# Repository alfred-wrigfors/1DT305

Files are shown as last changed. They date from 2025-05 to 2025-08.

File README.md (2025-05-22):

# 1DT305
Summer 2025 - Applied IoT

> [!NOTE]
> I, the author, have multiple years of experience in both embedded hardware design and software development. The level of complexity of this project is not reasonable for a beginner IoT-project!

## Introduction
With family living close to the Vikhög marina, there is the constant question wether or not the condition in/around the marina is appropriate for going swimming. It is mostly the water temperature and levels of wind that are of interest. Insight into the conditions in the marina would greatly increase the likelihood of spontaneous and enjoyable swims, while also helping to avoid unpleasant surprises - such as unexpected cold water or strong winds. Rather than relying on regional forecasts, a localized monitoring system would offer a much more accurate and timely solution.

This project aims to provide current and up-to-date temperature readings, for both the water and air, accross the marina and an overall wind speed and heading reading. The goal is to distribute 2-4 battery- and solar powered sensor-stations at the most popular areas for going swimming, communicating wirelessly with a base-station that is connected to the internet and sending the data to a remote server that provides the information (both current and historic) in a simple and intuitive web-interface.

## Goals and constraints
Some overall goals for the project:
 - Server / web interface containerized to run in a Docker container.
 - The base station and the mobile units should be electronically identical.
 - Hardware designed to be fully assebled by the PCB fab.
 - Be able to sustain one month (31 days) of operation without recharging the unit manually.
 - WiFi enabled.
 - USB-C (programming, serial debugging and power).
 - Temperature sensor (air and water)
 - Humidity sensor.
 - Light sensor (photoresisotr / phototransistor).
 - (Pressure sensor) [OPTIONAL]

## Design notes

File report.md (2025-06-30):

<!-- AUTO GENERATED -->

<!-- 1. Introduction.md -->
# Introduction
With family living close to the Vikhög marina, there is the constant question wether or not the condition in/around the marina is appropriate for going swimming. It is mostly the water temperature and levels of wind that are of interest. Insight into the conditions in the marina would greatly increase the likelihood of spontaneous and enjoyable swims, while also helping to avoid unpleasant surprises - such as unexpected cold water or strong winds. Rather than relying on regional forecasts, a localized monitoring system would offer a much more accurate and timely solution.

This project aims to provide current and up-to-date temperature readings, for both the water and air, accross the marina. The goal is to distribute 2-4 battery- and solar powered sensor-stations at the most popular areas for going swimming, communicating wirelessly over a 2.4 GHz WiFi link with the internet - sending the data to a remote server that provides the information (both current and historic) in a simple and intuitive web-interface.

## Goals and constraints
Some overall goals for the project:
 - Server / web interface containerized to run in a Docker enviroment.
 - Hardware designed to be fully assebled by the PCB fab (with excption for simple THT connectors and headers).
 - Be able to sustain one month (31 days) of operation without recharging the unit manually.
 - USB-C (programming, serial debugging and power).
 - Temperature sensor (air and water)
 - Humidity sensor.
 - Light sensor (photoresistor / phototransistor).
 - (Pressure sensor) [OPTIONAL]

<!-- 2. System Architecture.md -->
# System Architecture

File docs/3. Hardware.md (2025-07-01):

# Hardware

## ESP32
### Raspberry Pi Pico W

## Power
The power section of the hardware is the most complicated section. There are three different sources (USB, battery and solar), all at different and varying voltages, that need to be seamlessly switched between while operating.

The battery is the main power source while in operation with the solar panel and USB acting as secondary sources to charge the battery.l

## Sensors

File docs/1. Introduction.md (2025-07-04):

# Introduction
With family living close to the Vikhög marina, there is the constant question wether or not the condition in/around the marina is appropriate for going swimming. It is mostly the water and air temperature that are of interest. Insight into the conditions in the marina would greatly increase the likelihood of spontaneous and enjoyable swims, while also helping to avoid unpleasant surprises - such as unexpected cold water or cold winds. Rather than relying on regional forecasts, a localized monitoring system would offer a much more accurate and timely solution.

This project aims to provide current and up-to-date temperature readings, for both the water and air, accross the marina. The goal is to prototype 2-4 distributed battery- and solar powered sensor-stations at the most popular areas for going swimming, communicating wirelessly over a 2.4 GHz WiFi link with the internet - sending the data to a remote server that provides the information (both current and historic) in a simple and intuitive web-interface.

## Goals and constraints for finished device
Some overall goals for the project:
 - Server / web interface containerized to run in a Docker enviroment.
 - Hardware designed to be fully assebled by the PCB fab (with excption for simple THT connectors and headers).
 - Be able to sustain one month (31 days) of operation without recharging the unit manually.
 - USB-C (programming, serial debugging and power).
 - Temperature sensor (air and water)
 - Humidity sensor.
 - Light sensor (photoresistor / phototransistor).
 - Pressure sensor

## Goals and constraints for prototype device

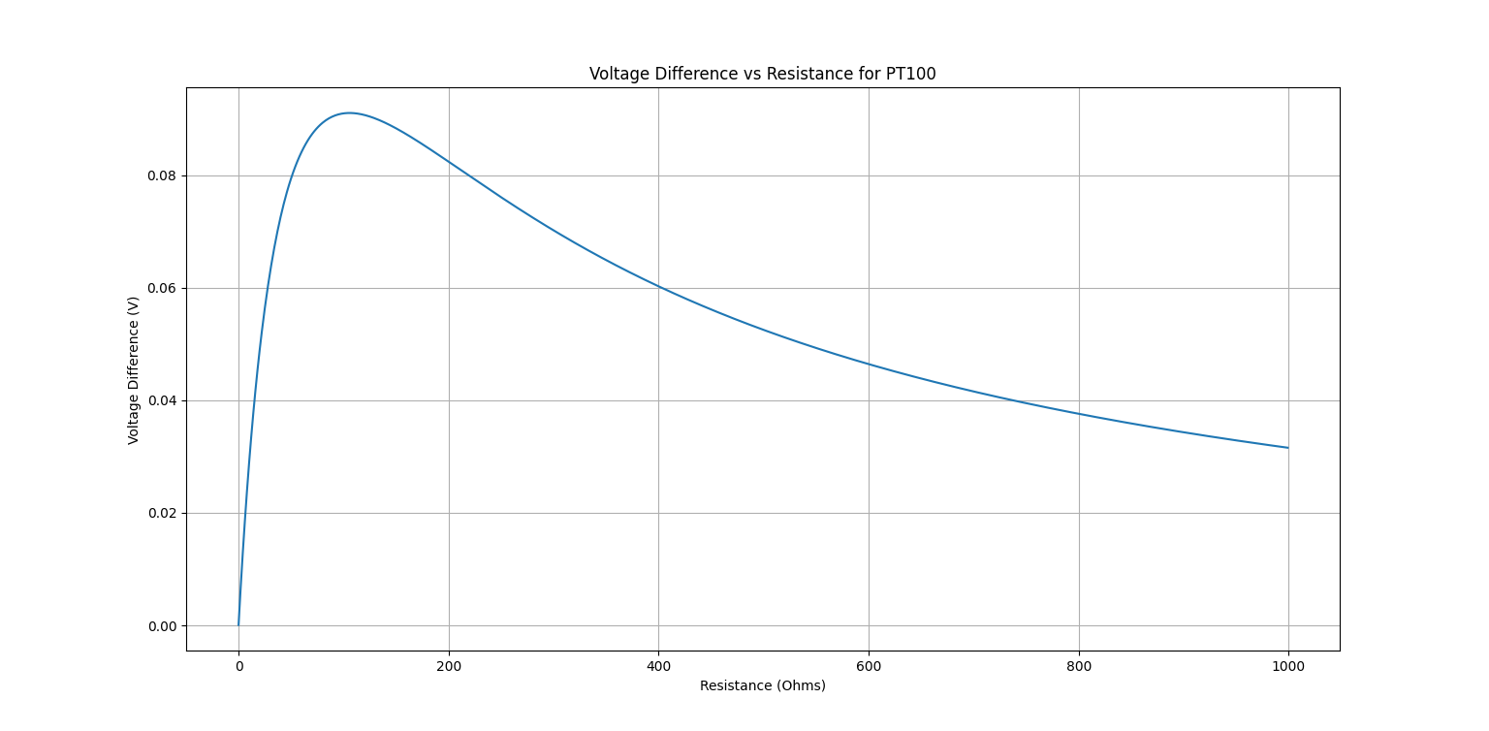
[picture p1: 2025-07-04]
hardware/Prototype/Simulated_Resistance.png

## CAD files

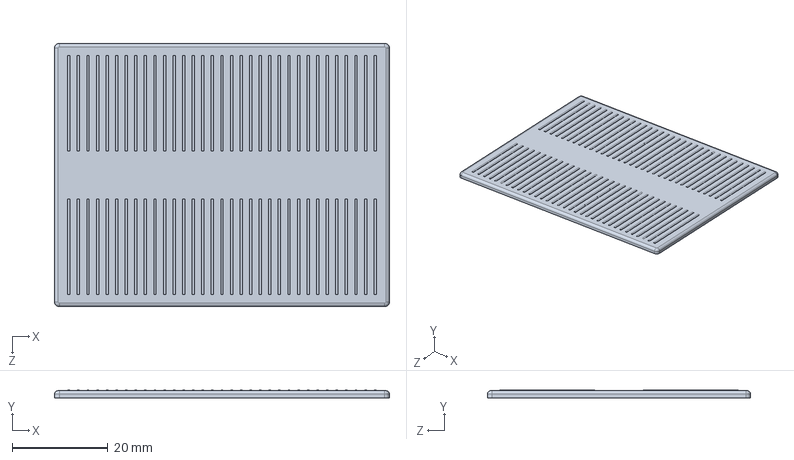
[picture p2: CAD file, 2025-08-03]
hardware/CAD/SOLAR_PLANEL.SLDPRT
70.0 x 1.60 x 55.0 mm

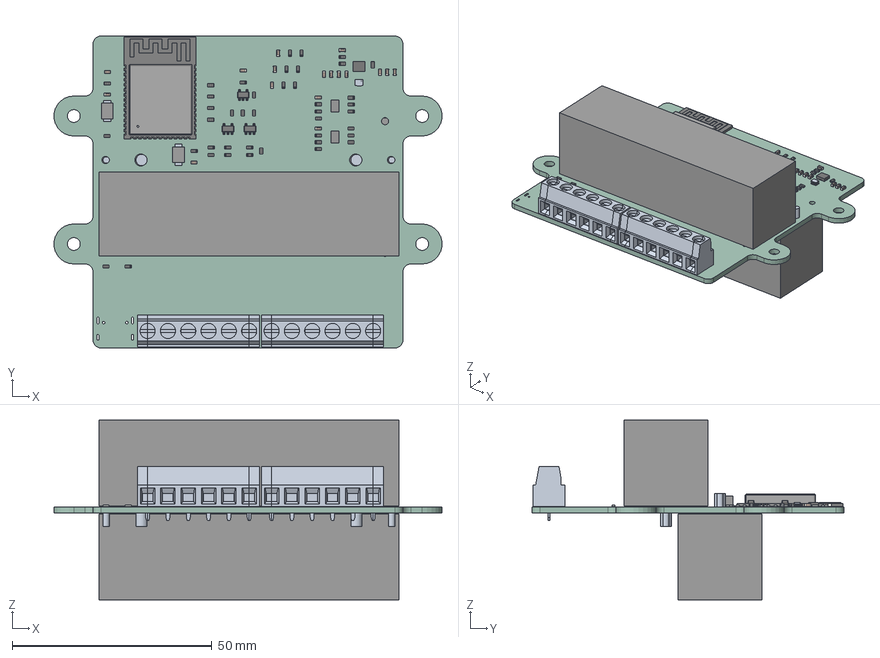
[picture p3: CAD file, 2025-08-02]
hardware/MarinaWatch.step
97.0 x 78.0 x 44.9 mm
C_0603_1608Metric x 17
DQC0010A_ASM x 2
R_0603_1608Metric x 42
L_Wurth_WE-LQSH-2010
ASSEMBLY x 4
Assem1 x 2
ESP32-S3-WROOM-1
RNM0015A_ASM
SOT_23_5 x 3
MarinaWatch_PCB

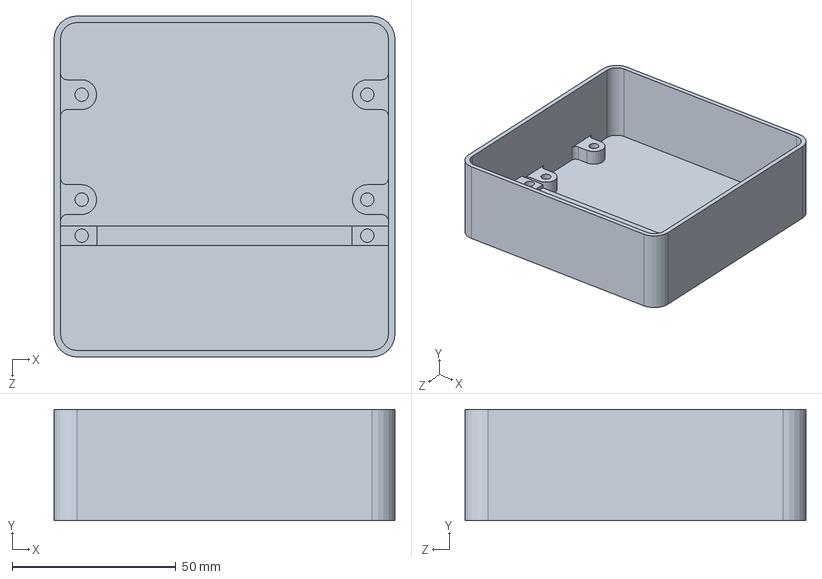
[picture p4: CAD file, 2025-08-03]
hardware/CAD/MARINAWATCH_BODY.SLDPRT
104.0 x 34.0 x 104.0 mm

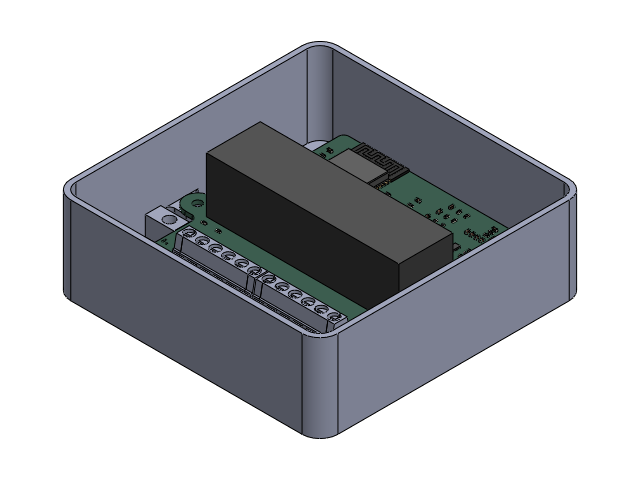
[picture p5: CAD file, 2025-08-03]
hardware/CAD/MARINAWATCH_MAIN.SLDASM
MARINAWATCH_BODY
C_0603_1608Metric-0.step x 17
DQC0010A_ASM.step x 2
R_0603_1608Metric-1.step x 42
L_Wurth_WE-LQSH-2010-2.step
ASSEMBLY.step x 2
ASSEMBLY-3.step
Assem1.step x 2
ESP32-S3-WROOM-1-4.step
RNM0015A_ASM.step
SOT_23_5.step x 3
MarinaWatch_PCB.step

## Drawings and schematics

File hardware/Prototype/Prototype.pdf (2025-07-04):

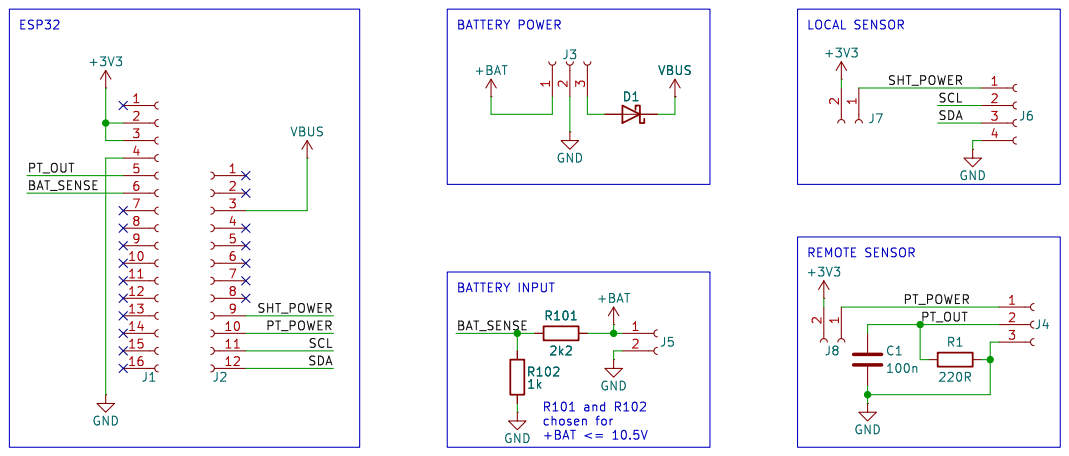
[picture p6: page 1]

Id: 1/1 Title: Applied IoT

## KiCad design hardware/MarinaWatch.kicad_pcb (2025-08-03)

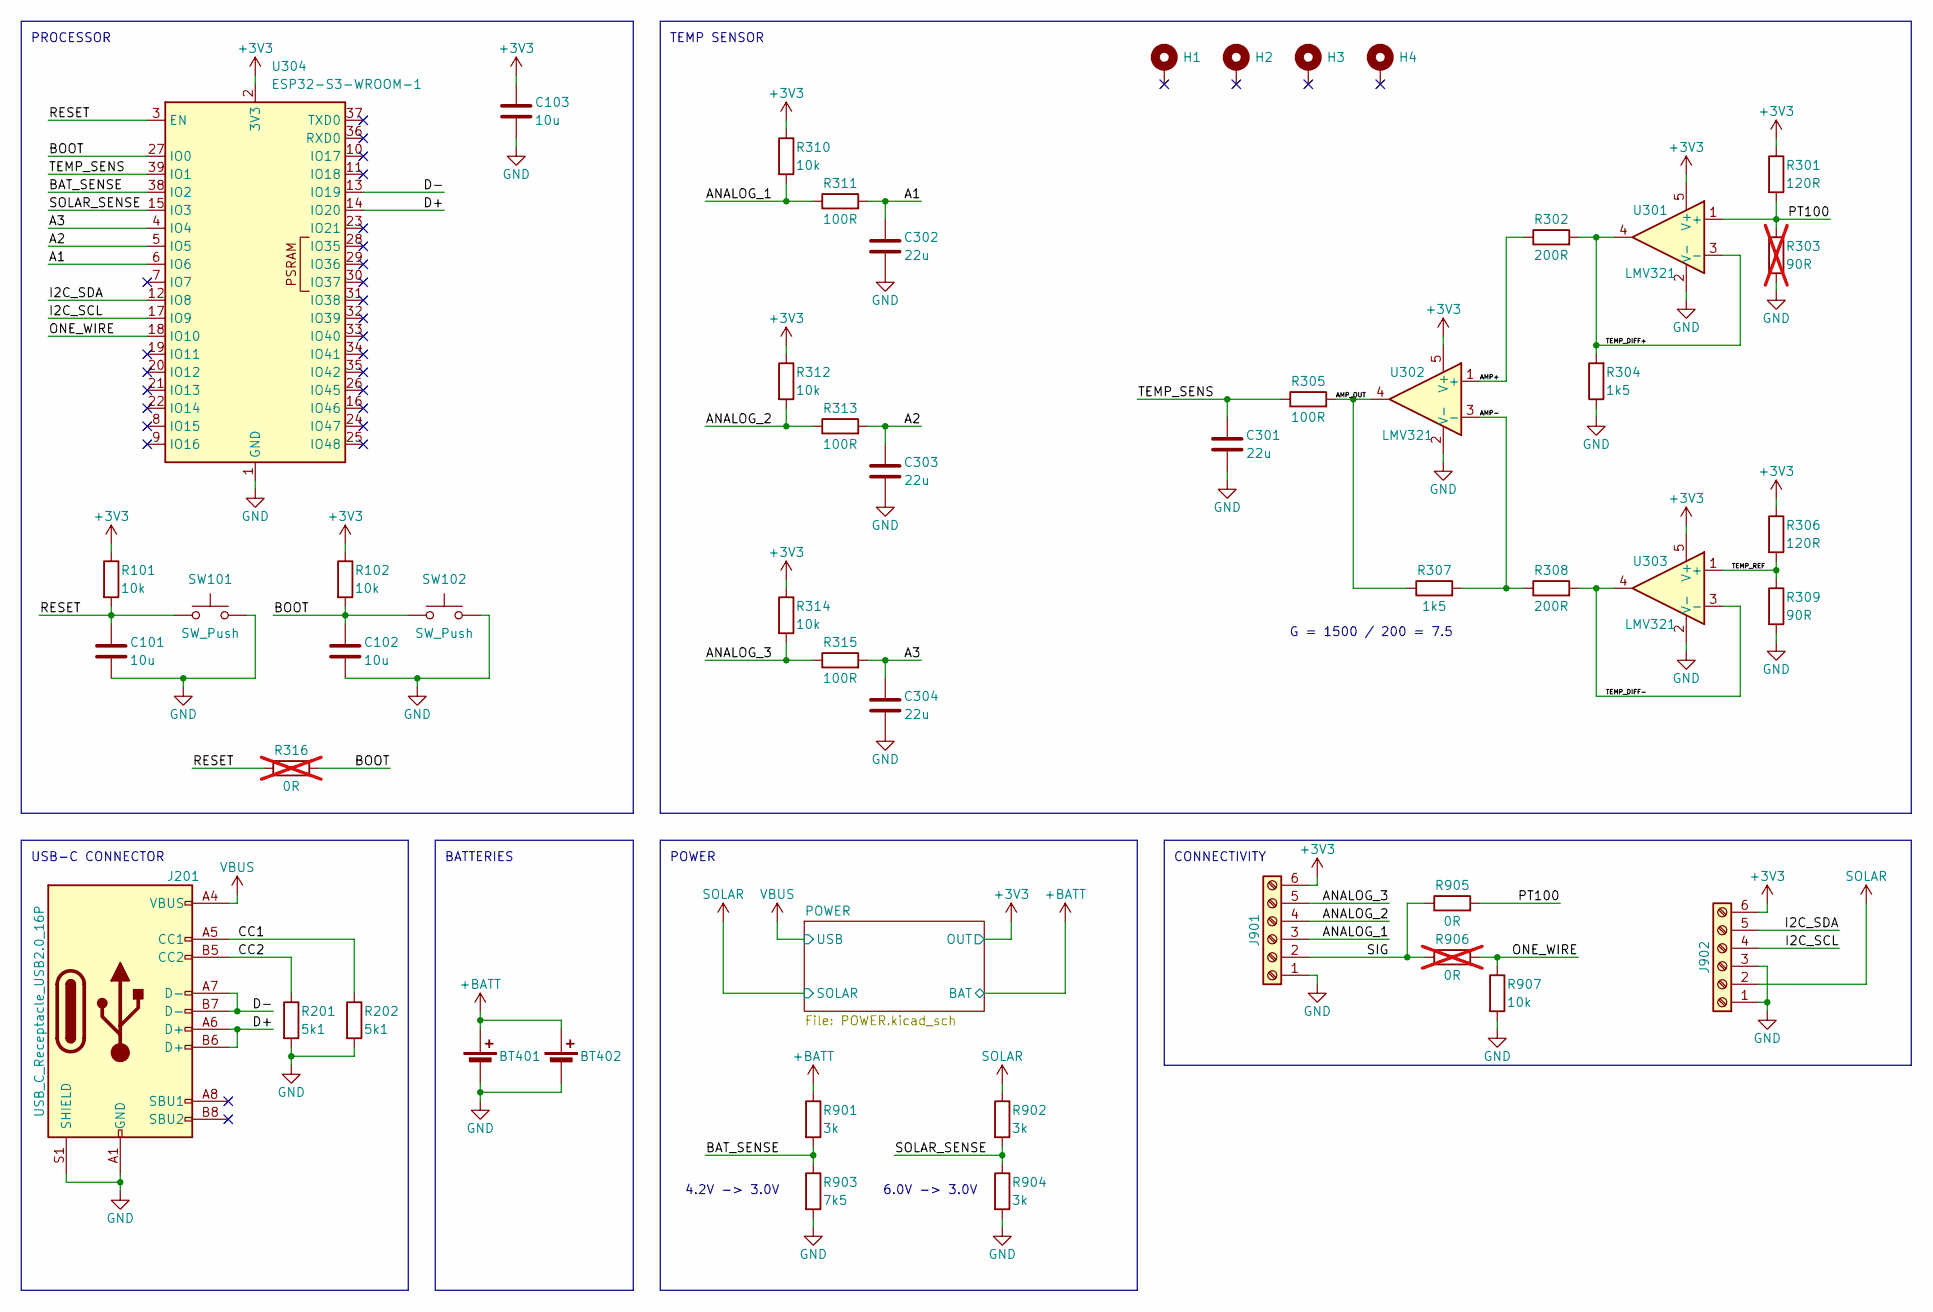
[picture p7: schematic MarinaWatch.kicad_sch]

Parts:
BT401, BT402: Battery_Cell; 18650
C101, C102, C103: 10u; C_0603_1608Metric_Pad1.08x0.95mm_HandSolder
C301, C302, C303, C304: 22u; C_0603_1608Metric_Pad1.08x0.95mm_HandSolder
H1, H2, H3, H4: MountingHole_Pad; MountingHole_3.2mm_M3_DIN965_Pad
J201: USB_C_Receptacle_USB2.0_16P; USB_C_Receptacle_G-Switch_GT-USB-7010ASV
J901, J902: Screw_Terminal_01x06; THT_SCREW_01x06_P5.08mm
R101, R102, R310, R312, R314, R907: 10k; R_0603_1608Metric_Pad0.98x0.95mm_HandSolder
R201, R202: 5k1; R_0603_1608Metric_Pad0.98x0.95mm_HandSolder
R301, R306: 120R; R_0603_1608Metric_Pad0.98x0.95mm_HandSolder
R302, R308: 200R; R_0603_1608Metric_Pad0.98x0.95mm_HandSolder
R303: 90R; R_0603_1608Metric_Pad0.98x0.95mm_HandSolder; not fitted
R304, R307: 1k5; R_0603_1608Metric_Pad0.98x0.95mm_HandSolder
R305, R311, R313, R315: 100R; R_0603_1608Metric_Pad0.98x0.95mm_HandSolder
R309: 90R; R_0603_1608Metric_Pad0.98x0.95mm_HandSolder
R316, R906: 0R; R_0603_1608Metric_Pad0.98x0.95mm_HandSolder; not fitted
R901, R902, R904: 3k; R_0603_1608Metric_Pad0.98x0.95mm_HandSolder
R903: 7k5; R_0603_1608Metric_Pad0.98x0.95mm_HandSolder
R905: 0R; R_0603_1608Metric_Pad0.98x0.95mm_HandSolder
SW101, SW102: SW_Push; BUTTON_SMD_3x4mm
U301, U302, U303: LMV321; SOT-23-5
U304: ESP32-S3-WROOM-1

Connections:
+3V3: C103.1, J901.6, J902.6, R101.1, R102.1, R301.1, R306.1, R310.1, R312.1, R314.1, U301.5 (V+), U302.5 (V+), U303.5 (V+), U304.2 (3V3); also elsewhere on the board
+BATT: BT401.1 (+), BT402.1 (+), R901.1; also elsewhere on the board
/A1: C302.1, R311.2, U304.6 (IO6)
/A2: C303.1, R313.2, U304.5 (IO5)
/A3: C304.1, R315.2, U304.4 (IO4)
/AMP+: R302.1, U302.1 (+)
/AMP-: R307.2, R308.1, U302.3 (-)
/AMP_OUT: R305.2, R307.1, U302.4
/ANALOG_1: J901.3, R310.2, R311.1
/ANALOG_2: J901.4, R312.2, R313.1
/ANALOG_3: J901.5, R314.2, R315.1
/BAT_SENSE: R901.2, R903.1, U304.38 (IO2)
/BOOT: C102.1, R102.2, R316.2, SW102.1, U304.27 (IO0)
/CC1: J201.A5 (CC1), R202.1
/CC2: J201.B5 (CC2), R201.1
/D+: J201.A6 (D+), J201.B6 (D+), U304.14 (IO20)
/D-: J201.A7 (D-), J201.B7 (D-), U304.13 (IO19)
/I2C_SCL: J902.4, U304.17 (IO9)
/I2C_SDA: J902.5, U304.12 (IO8)
/ONE_WIRE: R906.2, R907.1, U304.18 (IO10)
/PT100: R301.2, R303.1, R905.2, U301.1 (+)
/RESET: C101.1, R101.2, R316.1, SW101.1, U304.3 (EN)
/SIG: J901.2, R905.1, R906.1
/SOLAR_SENSE: R902.2, R904.1, U304.15 (IO3)
/TEMP_DIFF+: R302.2, R304.2, U301.3 (-), U301.4
/TEMP_DIFF-: R308.2, U303.3 (-), U303.4
/TEMP_REF: R306.2, R309.1, U303.1 (+)
/TEMP_SENS: C301.1, R305.1, U304.39 (IO1)
GND: BT401.2 (-), BT402.2 (-), C101.2, C102.2, C103.2, C301.2, C302.2, C303.2, C304.2, J201.A1 (GND), J201.A12 (GND), J201.B1 (GND), J201.B12 (GND), J201.S1 (SHIELD), J901.1, J902.1, J902.3, R201.2, R202.2, R303.2, R304.1, R309.2, R903.2, R904.2, R907.2, SW101.2, SW102.2, U301.2 (V-), U302.2 (V-), U303.2 (V-), U304.1 (GND), U304.40 (GND), U304.41 (GND); also elsewhere on the board
SOLAR: J902.2, R902.1; also elsewhere on the board
VBUS: J201.A4 (VBUS), J201.A9 (VBUS), J201.B4 (VBUS), J201.B9 (VBUS); also elsewhere on the board

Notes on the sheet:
BATTERIES
4.2V -> 3.0V
USB-C CONNECTOR
TEMP SENSOR
POWER
CONNECTIVITY
6.0V -> 3.0V
PROCESSOR
G = 1500 / 200 = 7.5

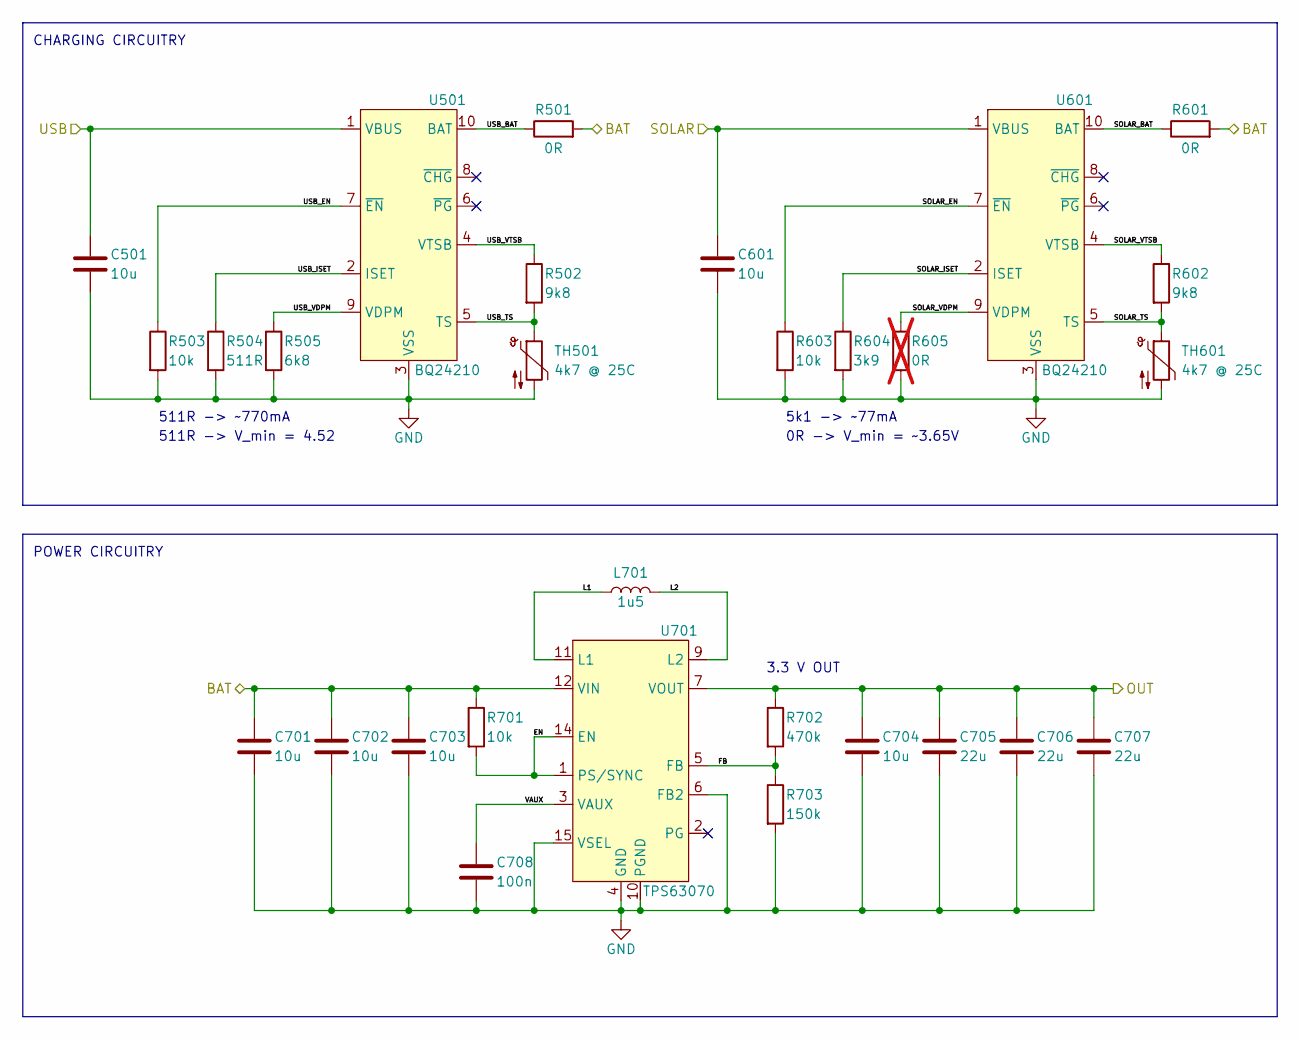
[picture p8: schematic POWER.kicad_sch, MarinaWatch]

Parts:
C501, C601, C701, C702, C703, C704: 10u; C_0603_1608Metric_Pad1.08x0.95mm_HandSolder
C705, C706, C707: 22u; C_0603_1608Metric_Pad1.08x0.95mm_HandSolder
C708: 100n; C_0603_1608Metric_Pad1.08x0.95mm_HandSolder
L701: 1u5; L_Wurth_WE-LQSH-2010
R501, R601: 0R; R_0603_1608Metric_Pad0.98x0.95mm_HandSolder
R502, R602: 9k8; R_0603_1608Metric_Pad0.98x0.95mm_HandSolder
R503, R603, R701: 10k; R_0603_1608Metric_Pad0.98x0.95mm_HandSolder
R504: 511R; R_0603_1608Metric_Pad0.98x0.95mm_HandSolder
R505: 6k8; R_0603_1608Metric_Pad0.98x0.95mm_HandSolder
R604: 3k9; R_0603_1608Metric_Pad0.98x0.95mm_HandSolder
R605: 0R; R_0603_1608Metric_Pad0.98x0.95mm_HandSolder; not fitted
R702: 470k; R_0603_1608Metric_Pad0.98x0.95mm_HandSolder
R703: 150k; R_0603_1608Metric_Pad0.98x0.95mm_HandSolder
TH501, TH601: 4k7 @ 25C; R_0603_1608Metric_Pad0.98x0.95mm_HandSolder
U501, U601: BQ24210; WSON-10
U701: TPS63070; VQFN-3.0x2.5

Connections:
+3V3: C704.1, C705.1, C706.1, C707.1, R702.1, U701.7 (VOUT), U701.8 (VOUT); also elsewhere on the board
+BATT: C701.1, C702.1, C703.1, R501.2, R601.2, R701.1, U701.12 (VIN), U701.13 (VIN); also elsewhere on the board
/POWER/EN: R701.2, U701.1 (PS/SYNC), U701.14 (EN)
/POWER/FB: R702.2, R703.1, U701.5 (FB)
/POWER/L1: L701.1, U701.11 (L1)
/POWER/L2: L701.2, U701.9 (L2)
/POWER/SOLAR_BAT: R601.1, U601.10 (BAT)
/POWER/SOLAR_EN: R603.1, U601.7 (~EN)
/POWER/SOLAR_ISET: R604.1, U601.2 (ISET)
/POWER/SOLAR_TS: R602.2, TH601.1, U601.5 (TS)
/POWER/SOLAR_VDPM: R605.1, U601.9 (VDPM)
/POWER/SOLAR_VTSB: R602.1, U601.4 (VTSB)
/POWER/USB_BAT: R501.1, U501.10 (BAT)
/POWER/USB_EN: R503.1, U501.7 (~EN)
/POWER/USB_ISET: R504.1, U501.2 (ISET)
/POWER/USB_TS: R502.2, TH501.1, U501.5 (TS)
/POWER/USB_VDPM: R505.1, U501.9 (VDPM)
/POWER/USB_VTSB: R502.1, U501.4 (VTSB)
/POWER/VAUX: C708.1, U701.3 (VAUX)
GND: C501.2, C601.2, C701.2, C702.2, C703.2, C704.2, C705.2, C706.2, C707.2, C708.2, R503.2, R504.2, R505.2, R603.2, R604.2, R605.2, R703.2, TH501.2, TH601.2, U501.3 (VSS), U601.3 (VSS), U701.4 (GND), U701.6 (FB2), U701.10 (PGND), U701.15 (VSEL); also elsewhere on the board
SOLAR: C601.1, U601.1 (VBUS); also elsewhere on the board
VBUS: C501.1, U501.1 (VBUS); also elsewhere on the board

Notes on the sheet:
3.3 V OUT
CHARGING CIRCUITRY
511R -> ~770mA
POWER CIRCUITRY
0R -> V_min = ~3.65V
511R -> V_min = 4.52
5k1 -> ~77mA

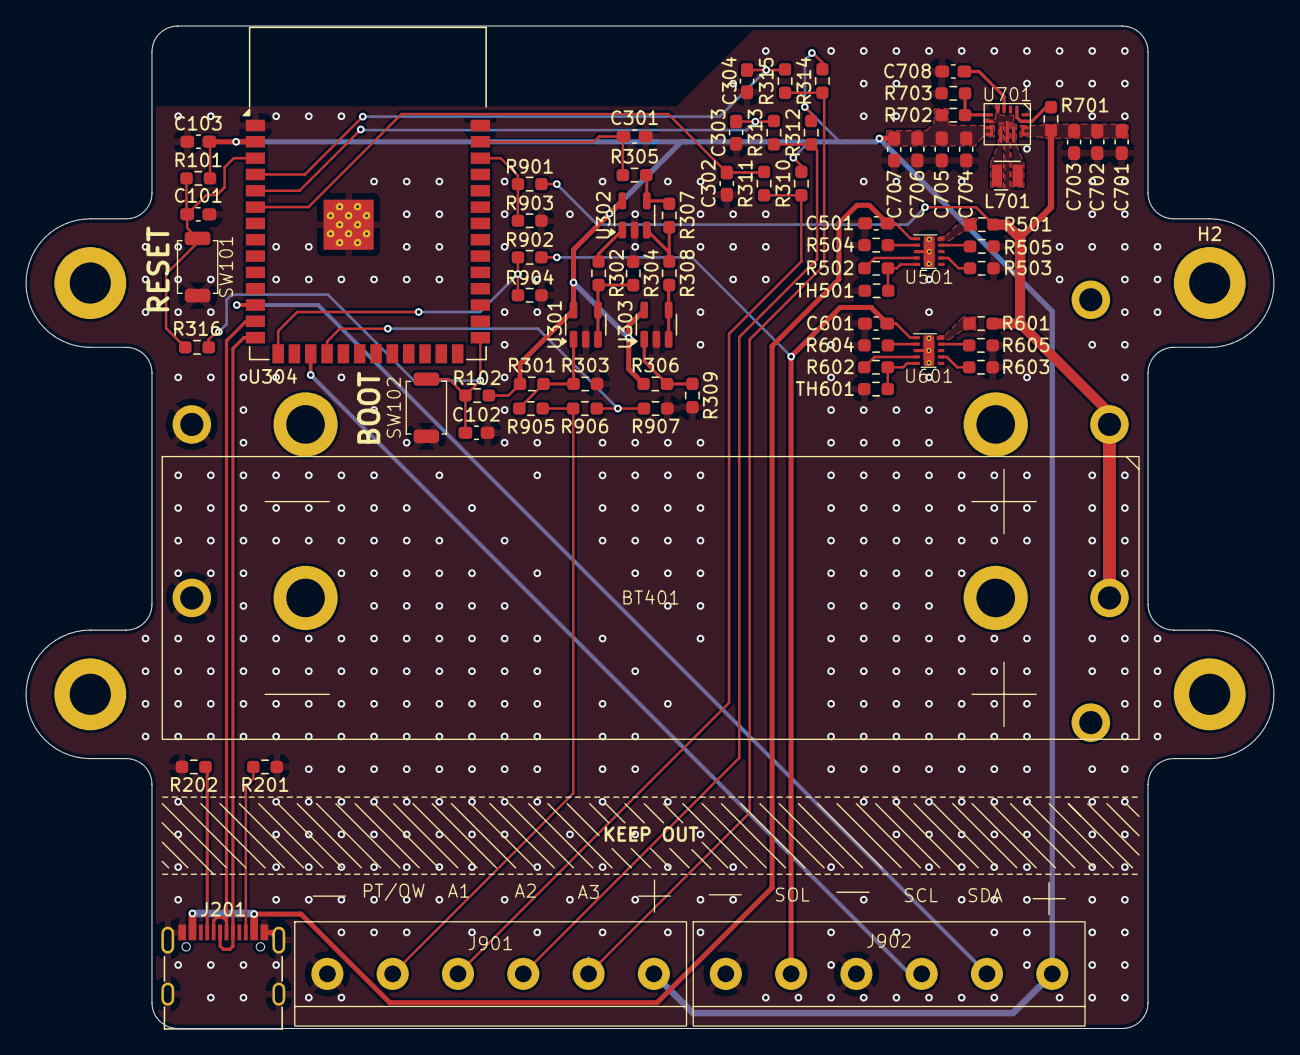
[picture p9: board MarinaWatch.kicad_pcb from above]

Board: 2 copper layers, 97.1 x 78.0 mm, 78 parts (1 on the bottom side), 48 nets.

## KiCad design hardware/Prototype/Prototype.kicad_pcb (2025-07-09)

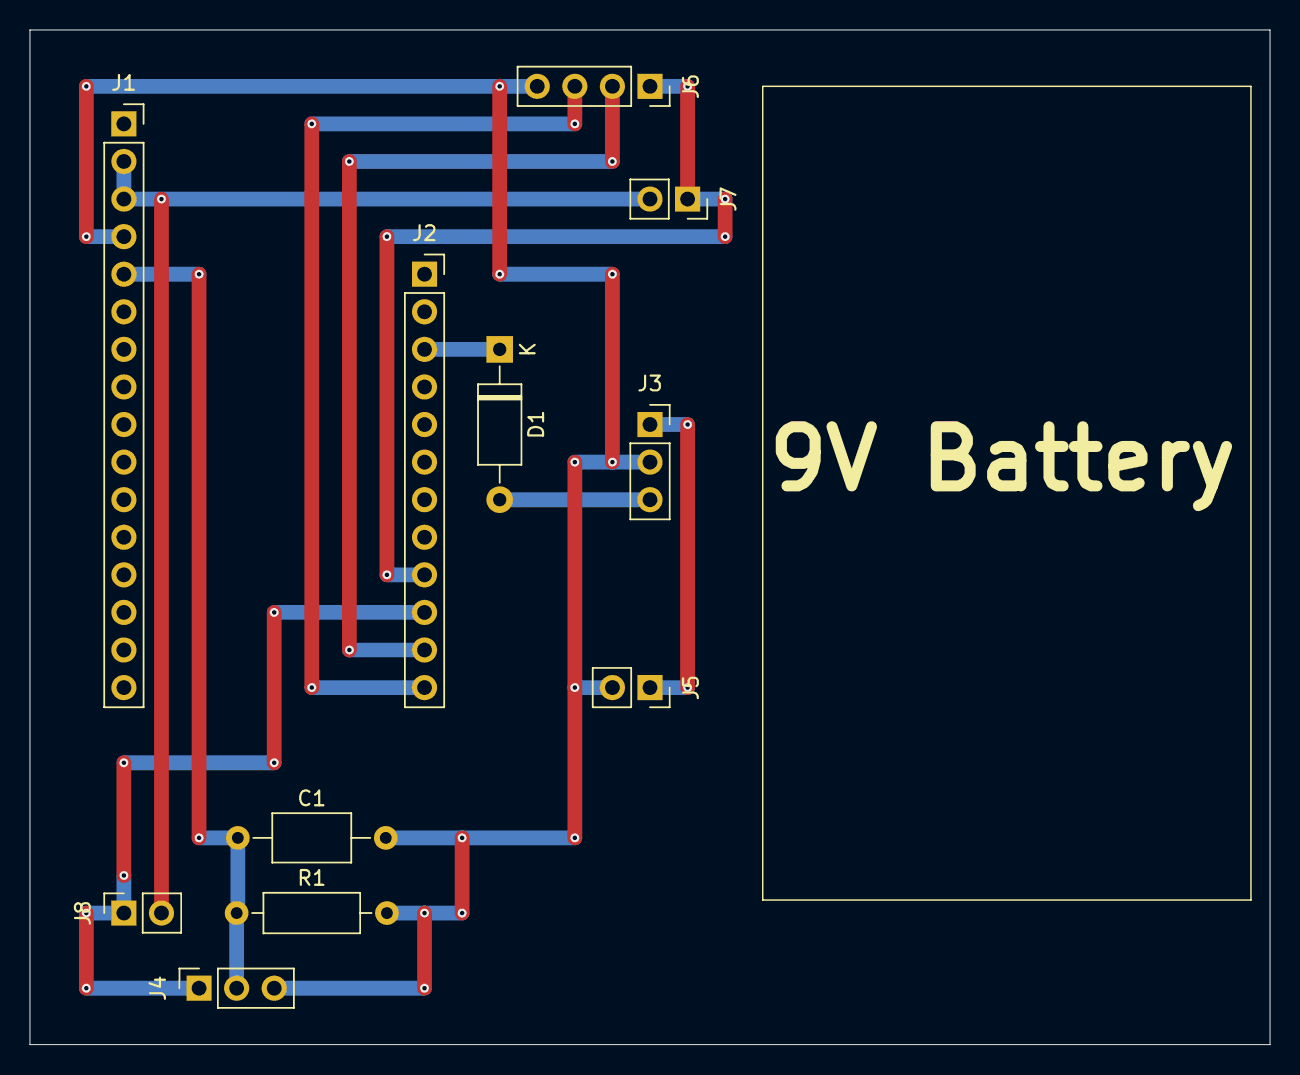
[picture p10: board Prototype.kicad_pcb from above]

Board: 2 copper layers, 83.8 x 68.6 mm, 11 parts (0 on the bottom side), 10 nets.

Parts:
C1: 100n; C_Axial_L5.1mm_D3.1mm_P10.00mm_Horizontal
D1: D_Schottky; D_A-405_P10.16mm_Horizontal
J1: Conn_01x16_Socket; PinSocket_1x16_P2.54mm_Vertical
J2: Conn_01x12_Socket; PinSocket_1x12_P2.54mm_Vertical
J3, J4: Conn_01x03_Socket; PinSocket_1x03_P2.54mm_Vertical
J5, J7, J8: Conn_01x02_Socket; PinSocket_1x02_P2.54mm_Vertical
J6: Conn_01x04_Socket; PinSocket_1x04_P2.54mm_Vertical
R1: 220R; R_Axial_DIN0207_L6.3mm_D2.5mm_P10.16mm_Horizontal

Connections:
+3V3: J1.2, J1.3, J7.2, J8.2
+BATT: J3.1, J5.1
/PT_OUT: C1.1, J1.5, J4.2, R1.1
/PT_POWER: J2.10, J4.1, J8.1
/SCL: J2.11, J6.2
/SDA: J2.12, J6.3
/SHT_POWER: J2.9, J6.1, J7.1
GND: C1.2, J1.4, J3.2, J4.3, J5.2, J6.4, R1.2
unnamed: D1.2 (A), J3.3
VBUS: D1.1 (K), J2.3

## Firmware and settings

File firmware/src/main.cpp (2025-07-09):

#include <WiFi.h>
#include <WiFiClient.h>
#include "SHT85.h"

#include "constants.hpp"

const int PIN_WATER   = A0;
const int PIN_BATTERY = A1;

float water     = 0;
float air       = 0;
float humid     = 0;
float voltage   = 0;
float soc       = 0;

void init();
void setup_wifi();
void read_sensors();
bool send_data();
void enter_sleep();

float calc_temp(int adc);
float calc_voltage(int adc);
float calc_soc(float voltage);

WiFiClient    client;
SHT30               sht(0x44);

void setup() { 

    init();

    setup_wifi();
}

void loop() {

    read_sensors();

    send_data();

    enter_sleep();
}

void init(){
    Wire.begin();
    Wire.setClock(100000);
    sht.begin();
    sht.isConnected();
    sht.readStatus();
    int status = sht.isConnected();
    status = sht.readStatus();

    pinMode(PIN_WATER, INPUT);      // PT Sensor
    pinMode(PIN_BATTERY, INPUT);    // Battery Voltage
}

void setup_wifi(){
    WiFi.begin(SSID, PASSWORD);
    while (WiFi.status() != WL_CONNECTED) { delay(500); }
}

void read_sensors(){
    for (size_t i = 0; i < 2; i++)
    {
        sht.read();
        delay(50);
    }    

    water   = calc_temp(analogRead(PIN_WATER));
    voltage = calc_voltage(analogRead(PIN_BATTERY));
    soc     = calc_soc(voltage);
    air     = sht.getTemperature();
    humid   = sht.getHumidity();
}


bool send_data(){

    if (!client.connect(SERVER, PORT)) { return false; }

    // Construct full URL path with query
    String url = "/" + String(ENDPOINT)  +  "?" + 
        "water=" + String(water, 2) + "&" +
        "air=" + String(air, 2) + "&" +
        "humid=" + String(humid, 2) + "&" +
        "voltage=" + String(voltage, 2) + "&" +
        "soc=" + String(soc, 2);


    client.print(String("GET ") + url + " HTTP/1.1\r\n" +
        "Host: " + SERVER + "\r\n" +
        "Connection: close\r\n\r\n");

    // Wait for response headers to end
    while (client.connected()) {
      String line = client.readStringUntil('\n');
      if (line == "\r") { break; }
    }

    // Read body
    String response = client.readString();

    if (response != "True"){ return false; }

    client.stop();

    return true;
}

void enter_sleep(){
    esp_sleep_enable_timer_wakeup(10 * 1000000);
    esp_deep_sleep_start();
}

float calc_temp(int adc){
    return (float)adc * TEMP_COEFF + TEMP_OFFSET;
}

float calc_voltage(int adc){
    return (float)adc / 4095 * 3.3 * BAT_COEFF;
}

float calc_soc(float voltage){
    return 100.0f * (voltage - BAT_MIN) / (BAT_MAX - BAT_MIN);
}

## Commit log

2025-04-29 Added initial HW
    [AirWarden.kicad_pcb, AirWarden.kicad_sch]
2025-05-17 Started with a simple battery simulation with solar
2025-05-22 Changed project
    [AirWarden.kicad_pcb, AirWarden.kicad_sch, MarinaWatch.kicad_pcb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]
2025-05-23 Finished USB hardware. Started power supply.
    [MarinaWatch.kicad_pcb, MarinaWatch.kicad_sch]
2025-05-25 Structure power supply chain
    [MarinaWatch.kicad_pcb, MarinaWatch.kicad_sch]
2025-06-12 Restarted HW and started testing ESP32 WiFi
    [MarinaWatch.kicad_pcb, MarinaWatch.kicad_sch]
2025-06-16 2.54mm THT prototype board
    [Prototype.kicad_pcb, Prototype.kicad_sch]
2025-06-21 Working prototype
2025-06-30 Start server side software
    [MarinaWatch.kicad_pcb, MarinaWatch.kicad_sch, Prototype.kicad_pcb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]
2025-07-02 Update current condidtions as well.
2025-07-06 Working on analog sensor
    [MarinaWatch.kicad_sch]
2025-07-06 Do not track .env
2025-07-07 Fix copy-paste issue for voltage and soc
2025-07-07 Calibrated voltage measurment against miltimeter
2025-07-09 Finished schematics for presentation
    [Prototype.kicad_pcb, Prototype.kicad_sch]
2025-07-22 Working on production version
    [MarinaWatch.kicad_sch]
2025-07-27 Restructure resistor calculations
2025-07-27 Added wheatstone bridge, battery chargers and 3v3 power supply
    [MarinaWatch.kicad_sch, POWER.kicad_sch]
2025-07-27 Started with calculations for amplifier stage
2025-07-28 Started with footprints and layout
    [MarinaWatch.kicad_pcb, MarinaWatch.kicad_sch, POWER.kicad_sch]
2025-07-29 Working on power circuitry layout
    [MarinaWatch.kicad_pcb, MarinaWatch.kicad_sch, POWER.kicad_sch]
2025-07-30 Layout almost finished (missing NTCs and Buttons)
    [MarinaWatch.kicad_pcb, MarinaWatch.kicad_sch]
2025-08-02 First draft of HW and moved scripts
    [MarinaWatch.kicad_pcb, MarinaWatch.kicad_sch, POWER.kicad_sch]
2025-08-02 Added NTCs
    [MarinaWatch.kicad_pcb, POWER.kicad_sch]
2025-08-02 Recond draft of HW
    [MarinaWatch-B_Cu.gbr, MarinaWatch-B_Mask.gbr, MarinaWatch-B_Paste.gbr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]
2025-08-03 Calculating values
    [MARINAWATCH_BODY.SLDPRT, MARINAWATCH_MAIN.SLDASM, MarinaWatch.kicad_pcb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]
